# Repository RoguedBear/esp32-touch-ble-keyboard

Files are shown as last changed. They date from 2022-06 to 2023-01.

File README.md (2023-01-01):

# esp32-touch-ble-keyboard

> A configurable bluetooth keyboard that utilizes the touch sensors on ESP32 as
> keyboard keys to send keystrokes to the connected device

https://user-images.githubusercontent.com/39442192/178109969-6f2e205e-52a7-4c5b-969b-fc063abdd287.mp4

<details>
  <summary><h2>why???????</h2></summary>

Since the past few months I've been noticing that when travelling with my laptop
some keys (`2`, `w`, `s`, `x`, `f5-8`) were just not responding on the hardware
level. Smacking the keys multiple times seemed to bring them back to life until
i travelled with my laptop again. \
But as time passed, even that method to beat life into my keys became a lost hope.

I didn't feel like spending on a new keyboard and I had an esp lying around,
so......

</details>

## 3d Printed case

custom case i designed to mount on my laptop's SD card reader to make the "keyboard"
even more portable

[preview the 3d `*.stl` files directly in github -->](https://github.com/RoguedBear/esp32-touch-ble-keyboard/tree/main/3D-case-files)

[note: final designs are different than the rendered video cuz i cant be bothered to update the video when the design updated too \\o_o/]

https://user-images.githubusercontent.com/39442192/188220671-781dfebc-abb5-4139-afbe-f23158edf579.mp4

## How to use

### Pre-requisites

open the project in VSCode and install platformio extension

### Keys layout

- define the pins and their corresponding letters you want to use in the file:
  [`includes/KEY_CONFIG.h`](https://github.com/RoguedBear/esp32-touch-ble-keyboard/blob/main/include/KEY_CONFIG.h#L4-L5)

- inside the `TOUCH_KEYS` array, initialise your keys using the format:
  ```
  TouchKey( <<pin number>>, '<<letter to press>>', <<optional threshold for *this* pin>> )
  ```
  (refer sample config in that file)

for the pin number, make sure to refer the pinout diagram of your ESP board and
select the touch pins only (touch pins are prefixed with `T`)

### Bluetooth device properties

- you can edit the device's bluetooth name, manufacturer's name & the battery
  level in [`include/CONFIG.h`](/include/CONFIG.h)

after you're done configuring, build the code and upload to your board

## ToDo

- [ ] improve touch processing algorithm to imitate a real keyboard's
- [x] make a 3d printed case

## Credits

This program uses the amazing
[`ESP32-BLE-Keyboard`](https://github.com/T-vK/ESP32-BLE-Keyboard) library made
by [T-vK](https://github.com/T-vK)

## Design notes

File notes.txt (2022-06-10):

big brain article explaining using say a queue, in ISR contexts & regular contexts
  https://joelfilho.com/blog/2021/interrupt_guards_c_cpp/
  
interrupt safe programs == reentrant program.
useful if im going to be using queue & interrupts
https://en.wikipedia.org/wiki/Reentrancy_(computing)

look into std::atomic maybe?

implement a "interrupt safe circular queue/buffer" maybe instead of linked list based queue?
https://stackoverflow.com/questions/14437797/interrupt-safe-buffer#14440477
https://www.downtowndougbrown.com/2013/01/microcontrollers-interrupt-safe-ring-buffers/

technical article explaining almost everything on ISRs and interrupts
http://www.gammon.com.au/interrupts

can dynamically generate ISR handlers by passing args & using lambda functions
https://forum.arduino.cc/t/using-isr-with-a-parameter/582169/13

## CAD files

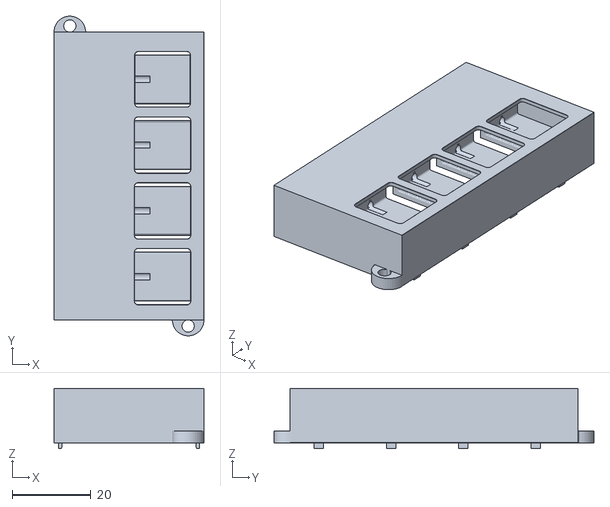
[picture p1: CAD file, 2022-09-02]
3D-case-files/upper half final.stl
38.0 x 81.0 x 15.3

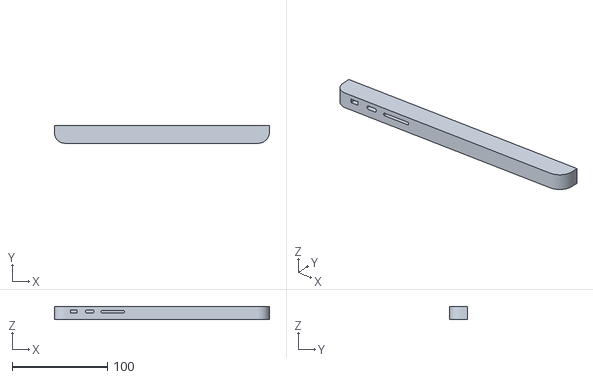
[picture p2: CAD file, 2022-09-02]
3D-case-files/laptop side reference model v4.stl
225.9 x 18.5 x 13.2

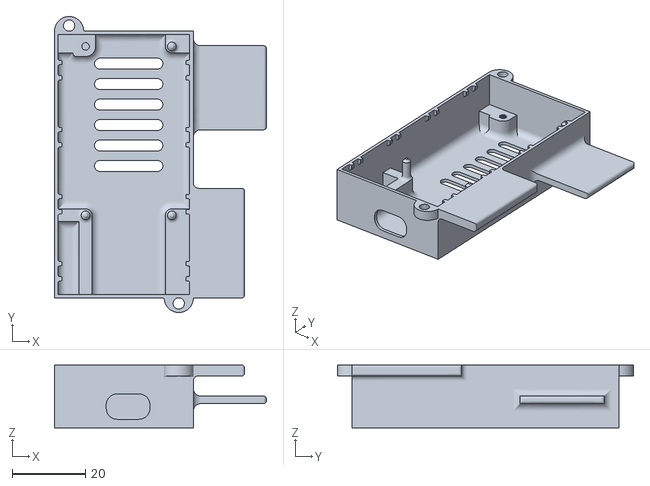
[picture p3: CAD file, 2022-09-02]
3D-case-files/lower half final.stl
58.0 x 81.0 x 17.2

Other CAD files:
3D-case-files/laptop side reference model v4.f3d

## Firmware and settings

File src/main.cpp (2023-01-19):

#include "CONFIG.h"
#include "CircularBuffer.h"
#include "KEY_CONFIG.h"
#include "TouchKey.h"
#include "utils/utils.h"

#include <Arduino.h>
#include <BleKeyboard.h>

BleKeyboard bleKeyboard(generate_suffix(KB_BLUETOOTH_NAME).c_str(),
                        KB_BLUETOOTH_MANUFACTURER_NAME,
                        KB_BLUETOOTH_BATTERY_LEVEL);

CircularBuffer<key_press_timestamp_t> buffer(BUFFER_SIZE);
key_press_timestamp_t                 discarded_ghost_touch;
unsigned long                         __led_last_on = 0;
unsigned long                         __last_bt_connected = 0;

void test_ISR_handler_arg(void *obj) {
    TouchKey *class_ptr = (TouchKey *)obj;
    buffer.push(class_ptr->generate_timestamp());
    // #ifdef DEBUG_CODE
    //     Serial.printf("got %c at %lu\n", class_ptr->letter_to_press,
    //     millis());
    // #endif
}

/**
 * Register ISR handlers for all the defined keys in the array
 * @param battery_mode if this flag is true, battery mode thresholds are used
 *                     instead of key-specific thresholds
 */
void register_ISR_handlers(bool battery_mode = false) {
    // using this because array size *is* known at compile time
    int array_len = sizeof(TOUCH_KEYS) / sizeof(TouchKey);

    for (int i = 0; i < array_len; i++) {
        TouchKey *key_obj = &TOUCH_KEYS[i];

        auto threshold = battery_mode ? ON_BAT_THRESHOLD : key_obj->threshold;

        touchAttachInterruptArg(key_obj->pin, test_ISR_handler_arg,
                                (void *)key_obj, threshold);
        Serial.printf("Registered handler for key '%c' at pin %d\n",
                      key_obj->letter_to_press, key_obj->pin);
    }
}

void setup() {
    // TODO: refactor all this
    pinMode(2, OUTPUT);
    Serial.begin(115200);

    auto battery_mode =
        detect_on_battery(TOUCH_KEYS, sizeof(TOUCH_KEYS) / sizeof(TouchKey));

    if (battery_mode) {
        // keyboard's battery level will be an indication
        // if battery mode is activated or not
        bleKeyboard.setBatteryLevel(battery_mode);
    }

    Serial.println("Registering touch interrupts");
    register_ISR_handlers(battery_mode != 0);

    Serial.println("Starting BLE work!");
    bleKeyboard.begin();

    while (!bleKeyboard.isConnected()) {
        digitalWrite(2, HIGH);
        delay(50);
        digitalWrite(2, LOW);
        delay(500);
    }
    buffer.clear();
    esp_sleep_enable_touchpad_wakeup();
}

void loop() {
    if (bleKeyboard.isConnected()) {
        digitalWrite(2, LOW);
        __last_bt_connected = millis();
        if (!buffer.is_empty()) {
#ifdef DEBUG_CODE
            String pre = buffer.print();
#endif
            key_press_timestamp_t timestamp      = buffer.pop();
            TouchKey *            key_obj        = timestamp.obj;
            unsigned long         old_last_touch = key_obj->last_touch_ms;

            /* Ghost touch prevention workaround */
            if (!buffer.is_empty() || discarded_ghost_touch.obj) {
                key_press_timestamp_t next_timestamp;
                if (!buffer.is_empty()) {
                    next_timestamp = buffer.poll();
                }
                // if we already discarded a ghost touch, check if the pins are
                // different
                if (discarded_ghost_touch.obj &&
                    discarded_ghost_touch.obj->pin != timestamp.obj->pin) {
                    next_timestamp = discarded_ghost_touch;
                }

                unsigned long delta = next_timestamp.time_recorded_ms -
                                      timestamp.time_recorded_ms;
                Serial.printf("path delta: %lu\n", delta);
                if (delta <= 100) { // ghost touches are recorded at the exact
                                    // same millisecond
                    discarded_ghost_touch = timestamp;
                    Serial.printf("Discarded ghost touch: %c, delta:%lu, "
                                  "current, next millis:%lu, %lu\n",
                                  timestamp.obj->letter_to_press, delta,
                                  timestamp.time_recorded_ms,
                                  next_timestamp.time_recorded_ms);
#ifdef DEBUG_CODE
                    Serial.println(pre + " \t||| \t" + buffer.print());
#endif
                    return;
                }
            }
            discarded_ghost_touch.obj = NULL;

            if (key_obj->process_touch(timestamp)) {
                bleKeyboard.write(key_obj->letter_to_press);

                Serial.printf(
                    "Timestamp: letter:%d|%c last_recorded_ms:%lu \tmillis: "
                    "%lu \tdelta new:%lu\n\n",
                    key_obj->letter_to_press, key_obj->letter_to_press,
                    timestamp.last_touch_ms, timestamp.time_recorded_ms,

                    timestamp.time_recorded_ms - old_last_touch);
            }
#ifdef DEBUG_CODE
            Serial.println(pre + " \t||| \t" + buffer.print());
#endif
        }

    } else {
        unsigned long now = millis();
        if (now - __led_last_on >= 500) {
            __led_last_on = now;
            digitalWrite(2, HIGH);
            delay(50);
            digitalWrite(2, LOW);
        }

        buffer.clear();

        if (now - __last_bt_connected >= DEEP_SLEEP_TIMEOUT_min * 60 * 1000) {
            esp_deep_sleep_start();
        }
    }

    delay(10);
}
int main() {}

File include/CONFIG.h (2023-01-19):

#ifndef __CONFIG_h
#define __CONFIG_h

#define KB_BLUETOOTH_NAME              "ESP32 Keyboard" // 15 char limit
#define KB_BLUETOOTH_MANUFACTURER_NAME "CaaS Inc."
#define KB_BLUETOOTH_BATTERY_LEVEL     68

#define BUFFER_SIZE          4   // buffer size to maintain
#define KEY_PRESS_TIMEOUT_ms 400 // delay in milliseconds between key presses
#define TOUCH_THRESHOLD      20  // touch threshold used to detec touch
#define ON_BAT_THRESHOLD     30  // overrides other thresholds on battery mode

// if keyboard is not connected to a device for more than 5 minutes, esp will go
// to deep sleep and can be woken up by pressing the touch pad
#define DEEP_SLEEP_TIMEOUT_min 5

// ================== EXPERIMENTAL!!! ==================
// if you want to have the keyboard's name be greater than 15 characters, you
// have to modify the ESP32-BLE-Keyboard library and remove the part where name
// is trimmed to 15 characters. After doing that you may take advantage of the
// random emojis im appending at the end of the name
#define OVERRIDE_15_CHAR_LIMIT false

#endif

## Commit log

2022-06-12 add another test that covers a sample run
2022-07-05 enable esp stack trace decoding in new env
2022-07-06 add debug code that prints the buffer
2022-07-07 modify debug prints
2022-07-07 made workarounds to prevent ghost touches
    in my esp atleast, sometimes happens a little often, when touching a key/touch pin, the ISR is called for the currently touched pin/key and also for the key pressed *before* it at the exact same millisecond.
    couldn't figure out if it's hardware or a inbuilt software issue, but what i know for sure is those touches originate from the ISR.
    But now the code can handle `n` ghost touches happening at the same millisecond.
    coded & commit message written via the help of my esp keyboard :wholesome:
    [main.cpp]
2022-07-08 instead of characters, use pin numbers to discard ghost touches
2022-07-08 add config options to change various options
    - ble name, manufacture, battery
    - buffer size
    - time duration b/w key presses
2022-07-09 clear buffer when not connected + blink leds
2022-09-02 add 3d printable case demo
2022-09-02 add 3d case stl files
    [laptop side reference model v4.f3d, laptop side reference model v4.stl, lower half final.stl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]
2023-01-19 added battery mode: dynamically change key touch threshold
    when the kb is powered on, it will use the default configured threshold
    in `TOUCH_THRESHOLD` or if defined individually for a key.
    But when the laptop is on battery, sometimes the values when a key is
    touched won't go below the default threshold.
    But setting the default threshold too high to accomodate for the battery
    mode result in neighbouring keys to be detected as
    "touched", since then the value read from the touch pin lies between
    0-7, whereas on battery the
    values vary alot in the range 15-30
    To dynamically detect when to use the secondary threshold tailored for
    laptop being on battery, the user has to touch one of the keys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
    [CONFIG.h, main.cpp]
2023-01-19 keyboard goes to sleep 5 minutes after not being connected to any device
    to wakeup: press any of the touchpad.
